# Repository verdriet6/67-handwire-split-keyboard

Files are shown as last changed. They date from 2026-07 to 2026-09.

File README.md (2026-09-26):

# the brainrot keyboard of your dreams! :))
full ds
a handwired split mechanical keyboard running on qmk firmware consisting of 12 keys.

## about the project:
this is a handwired split mechanical keyboard made for the the love of the game (and tung tung tung sahur), it has a 3d printed enclosure that is shaped like the number 6 and 7. the heart of this device is the arduino pro micro, each enclosure consisting of one each and working as master and slave. other components include cherry mx key switches, braille keycaps, diodes, m3 screws along with heat inserts. 

## to build your own 67 keyboard:

buy the components as mentioned in the [bill of materials](https://github.com/touh6/67-handwire-split-keyboard/tree/main/bill%20of%20materials).

3d print the enclosures (files of which you can find in the [cad folder](https://github.com/touh6/67-handwire-split-keyboard/tree/main/cad))
and use this assembly guide:

1) place the case,
case

2) insert the bottom plates + heat inserts, 
case with bottom

3) use m3 screws to thread the case and the bottom plates, 
back of the case

4) insert the mcu's + trrs connectors, 
case with electronics

5) insert the switch plates, 
switch plate

6) place the key-switches, 
key-switches assembled

7) place the key-caps,
assembled 67

and you're all good to go! :))

## schematic:
v9
built using kicad

## gallery:
<table><tr>
      <h2 align="center">front & back: </h2>
  <td></td>
    <td></td>
</tr></table>

<table><tr>
      <h2 align="center">left & right view: </h2>
   <td><img src="https://github.com/user-attachments/assets/5f41dbc1-d7ed-4c95-a8d3-af9cbbb59c83""></td>
    <td></td>
</tr></table>

## tools i used:
<ul style="list-style-type:none;">
    <li>schematics: <a href="https://www.kicad.org">kicad</a></li>
    <li>cad: <a href="https://www.solidworks.com">solidworks</a></li>
    <li>zine: <a href="https://www.canva.com">canva</a></li>
</ul>

## bill of materials: 
|name |quantity  |cost|link|
|---|---|---|-----|
|1) Arduino Pro Micro| 2|  $9.21 |[link](https://robu.in/product/pro-micro-5v-16m-mini-leonardo-micro-controller-development-board-for-arduino/)|
|2) Diode 1N4148 | 12|  $0.08 |[link](https://www.ktron.in/product/diode-1n4148-th/)|
|3)  28 SWG copper wire | 1|  $0.21  |[link](https://www.electroncomponents.com/copper-wire-enamelled-28-awg-meters)|
|4) Cherry MX Switches| 35|  $15.89 |[link](https://keychron.in/product/cherry-mx-switch-set/)|
|5) Heat Inserts| 25|  $0.94 |[link](https://robu.in/product/m3-x-4-mm-brass-heat-set-knurl-threaded-round-insert-nut-25-pcs/)|
|6) M3 Screws | 10|  $2  |[link](https://rpishop.in/products/phillips-csk-m3)|
|7) TTRS Cable | 1|  $12.19 |[link](https://www.amazon.in/CableCreation-Auxiliary-4-Conductor-Microphone-Compatible/dp/B01K3WY93I)|
|shipping  | | $3.17 | |
| | total  |$43.66 |  |  |

as of 21st june 2026

## zine:
breadplayer

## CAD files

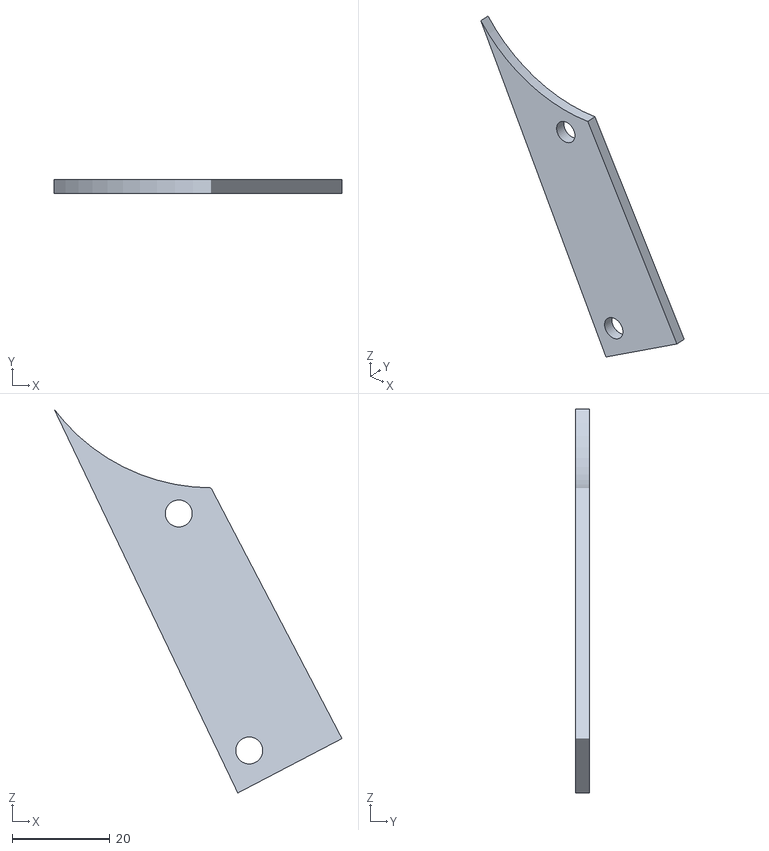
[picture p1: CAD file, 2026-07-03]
cad/stl (printing-legion)/6-top bottom.STL
58.8 x 2.79 x 78.4

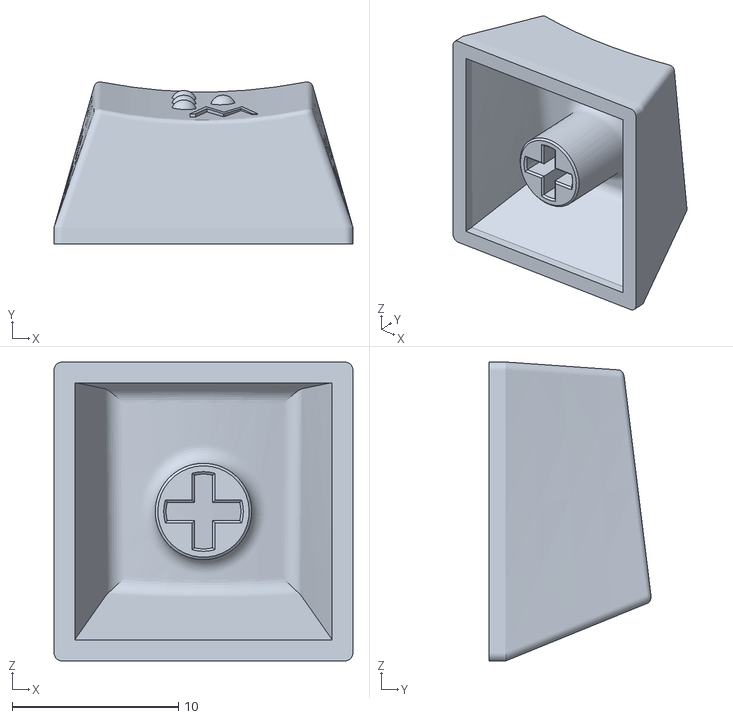
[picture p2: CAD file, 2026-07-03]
cad/stl (printing-legion)/keycaps/BD99-001-0000023 - BRAILLE CAP - W - NRL 20211114.STL
18.0 x 9.75 x 18.0

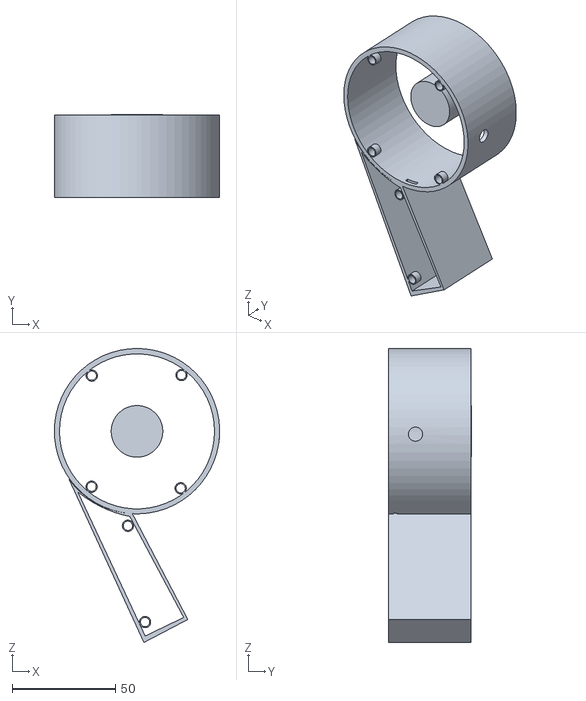
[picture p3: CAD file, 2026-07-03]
cad/stl (printing-legion)/6-case.STL
80.0 x 40.0 x 142.3

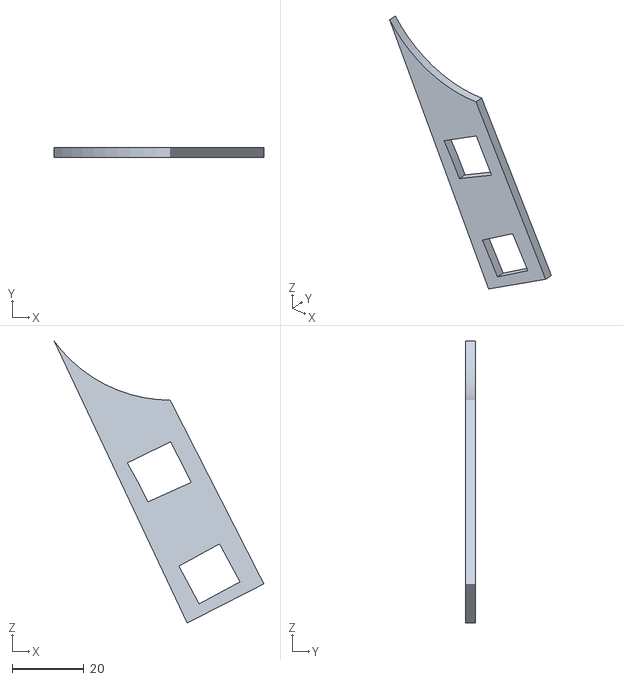
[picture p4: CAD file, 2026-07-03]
cad/stl (printing-legion)/6-switch top.STL
58.5 x 2.79 x 78.6

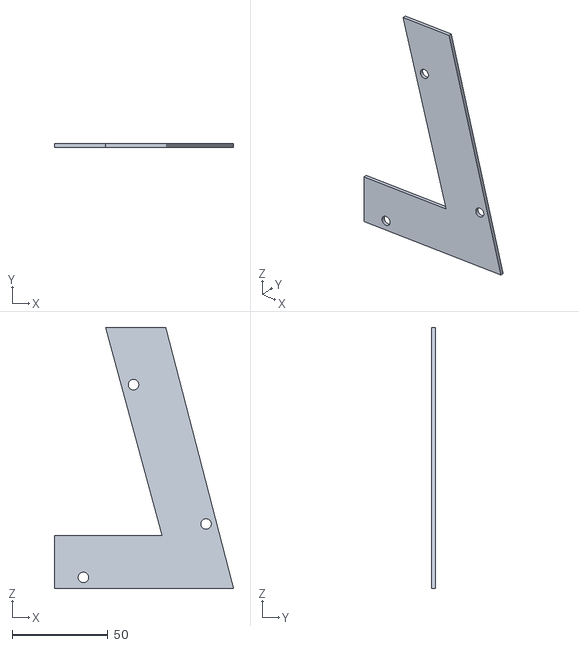
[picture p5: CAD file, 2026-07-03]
cad/stl (printing-legion)/7-bottom.STL
93.4 x 2.00 x 135.9

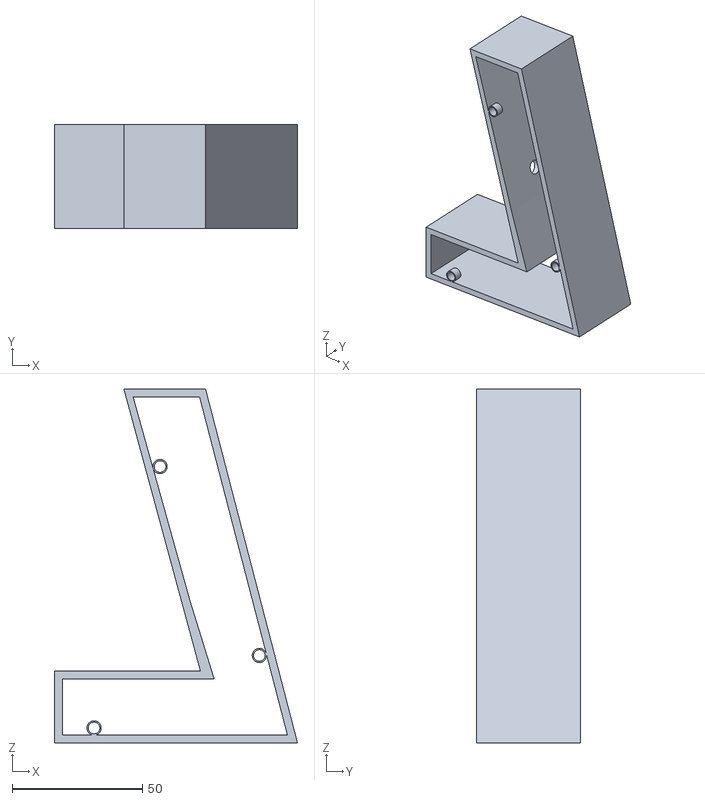
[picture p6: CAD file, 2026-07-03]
cad/stl (printing-legion)/7-case.STL
93.4 x 40.0 x 135.9

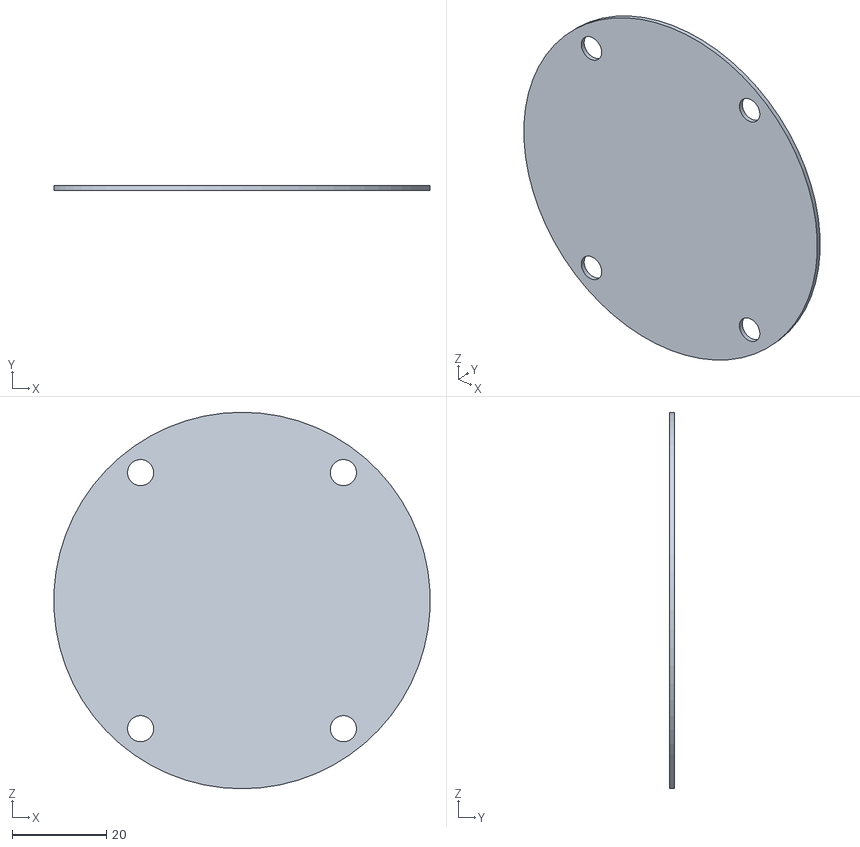
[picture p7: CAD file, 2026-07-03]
cad/stl (printing-legion)/6-bottom.STL
79.9 x 1.00 x 80.0

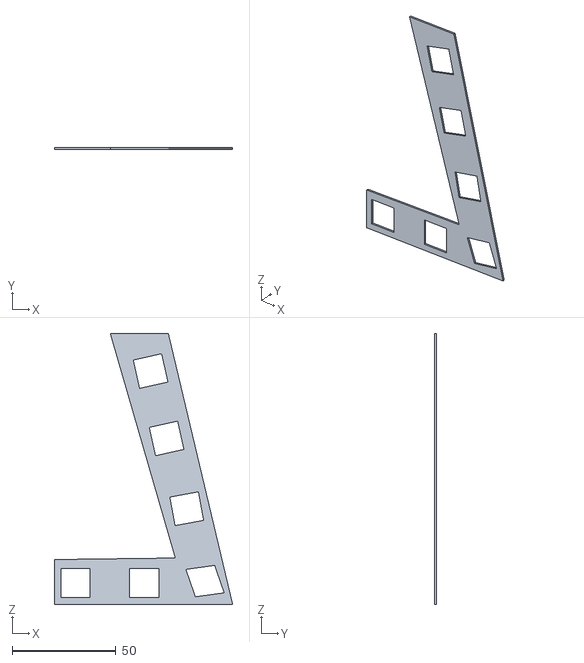
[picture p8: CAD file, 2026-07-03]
cad/stl (printing-legion)/7-switch plane.STL
86.0 x 1.00 x 130.6

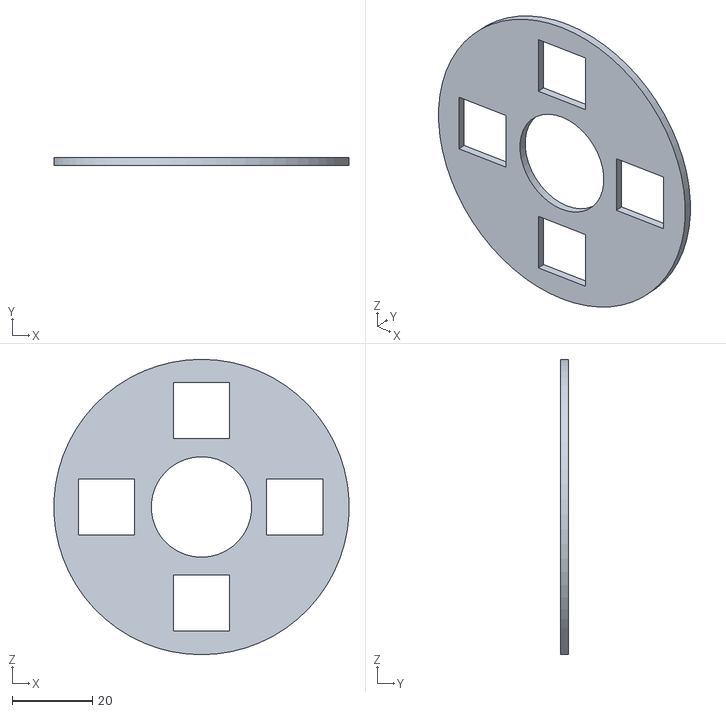
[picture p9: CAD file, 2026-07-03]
cad/stl (printing-legion)/6-switch plate bottom.STL
73.4 x 2.00 x 73.5

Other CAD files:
cad/stl (printing-legion)/keycaps/BD99-001-0000001 - BRAILLE CAP - A - NRL 20211114.STL
cad/stl (printing-legion)/keycaps/BD99-001-0000015 - BRAILLE CAP - O - NRL 20211114.STL
cad/stl (printing-legion)/keycaps/BD99-001-0000012 - BRAILLE CAP - L - NRL 20211114.STL
cad/stl (printing-legion)/keycaps/BD99-001-0000010 - BRAILLE CAP - J - NRL 20211114.STL
cad/stl (printing-legion)/keycaps/BD99-001-0000011 - BRAILLE CAP - K - NRL 20211114.STL
cad/stl (printing-legion)/keycaps/BD99-001-0000005 - BRAILLE CAP - E - NRL 20211114.STL
cad/stl (printing-legion)/keycaps/BD99-001-0000019 - BRAILLE CAP - S - NRL 20211114.STL
cad/stl (printing-legion)/keycaps/BD99-001-0000004 - BRAILLE CAP - D - NRL 20211114.STL
cad/stl (printing-legion)/keycaps/BD99-001-0000017 - BRAILLE CAP - Q - NRL 20211114.STL
cad/stl (printing-legion)/keycaps/BD99-001-0000009 - BRAILLE CAP - I - NRL 20211114.STL
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
